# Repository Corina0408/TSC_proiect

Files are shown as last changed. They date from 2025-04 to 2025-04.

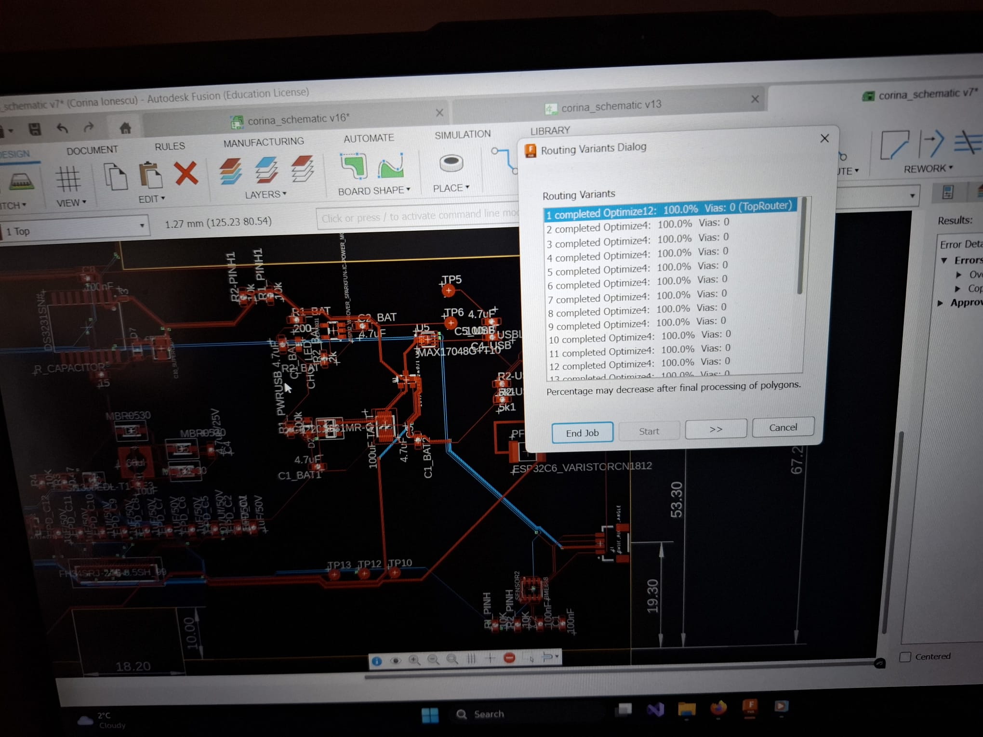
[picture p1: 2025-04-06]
Images/Screenshot 2025-04-06 214750.jpeg

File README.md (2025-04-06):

link diagrama bloc: https://files.fm/u/eejnjsv4u4 

link Bill of Materials: https://docs.google.com/spreadsheets/d/1bhhom45KiLlfx5yxiHwmtoe4DynNoX60qw5_dlvZoLE/edit?usp=sharing 

Descrierea functionalitatii: 

	dispozitiv smart, construit in jurul microcontrollerului ESP32-C6, care integreaza senzori de afisaj OLED, LED RGB pentru vizual, control tactil si un potentiometru.

	Module si componente utilizate

    ESP32-C6: microcontroller principal, care gestioneaza toate componentele, comunicarea si logica dispozitivului

    BME280: senzor de temperatura, umiditate si presiune

    Display OLED (SSD1306): afiseaza informatii de la senzori si statusul sistemului

    LED RGB WS2812B: ofera feedback vizual configurabil

    TTP223: buton tactil folosit pentru interactiuni simple, cum ar fi pornirea luminii sau schimbarea modului de afisare

    Potentiometru: permite reglarea unui parametru analogic

    Reed switch: senzor magnetic digital, detecteaza apropierea unui magnet

	Interfete si comunicatie

    I2C: folosita pentru a conecta atat senzorul BME280, cat si display-ul OLED pe acelasi bus. ESP32-C6 gestioneaza ambele componente fara conflicte.

    PWM/One-wire: pentru LED-ul WS2812B, controlat prin semnal digital specific.

    Digital input: pentru butonul capacitiv si reed switch.

    Analog input (ADC): pentru citirea potentiometrului.

Procesare si comportament

ESP32-C6 colecteaza datele de la senzori si le afiseaza pe ecran. In plus, permite interactiuni tactile si vizuale cu utilizatorul

Descrierea pinilor ESP32-C6:

BME280 (I2C)

    GPIO8 (SDA) – Bus I2C partajat cu display

    GPIO9 (SCL)

OLED SSD1306 (I2C)

    GPIO8 (SDA) – Partajare eficienta de pini

    GPIO9 (SCL)

WS2812B (PWM)

    GPIO7 – Output digital cu timing precis

TTP223 (Digital)

    GPIO6 – Pin liber, ideal pentru input

Potentiometru (Analog)

    GPIO4 (ADC1) – Suporta ADC, masoara tensiune

Reed switch (Digital)

    GPIO5 – Citire stare logica simpla

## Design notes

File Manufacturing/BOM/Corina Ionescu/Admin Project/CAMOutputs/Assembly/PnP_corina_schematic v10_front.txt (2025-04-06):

BOOT_BUTTON	63.88	122.91	180.00		MYBUTTON
C1	158.75	19.05	90.00	100nF	ESP32_WROVER_EAGLE-LTSPICE_C0402
C10	27.43	119.89	270.00	100nF	ESP32_WROVER_EAGLE-LTSPICE_C0402
C10_SUPERCAP	96.52	68.58	270.00	CPH3225A	CAPCP3225X100N
C1_BAT	115.57	68.58	270.00	4.7uF	ESP32_WROVER_EAGLE-LTSPICE_C0402
C1_BAT1	119.38	48.26	180.00	4.7uF	EAGLE-LTSPICE_C0402
C1_BAT2	135.89	52.07	270.00	4.7uF	ESP32_WROVER_EAGLE-LTSPICE_C0402
C2	154.94	19.05	90.00	100nF	ESP32_WROVER_EAGLE-LTSPICE_C0402
C2_BAT	128.27	71.12	0.00	4.7uF	ESP32_WROVER_EAGLE-LTSPICE_C0402
C3	130.81	54.61	270.00	100uF TANT	RCL_CT3528
C4	102.49	51.69	90.00	4.7uF/25V	ESP32_WROVER_EAGLE-LTSPICE_C0402
C4_USB	148.59	68.58	180.00	100nF	EAGLE-LTSPICE_C0402
C5	52.58	119.13	270.00	1uF	ESP32_WROVER_EAGLE-LTSPICE_C0402
C5_USB	148.59	71.12	180.00	4.7uF	EAGLE-LTSPICE_C0402
C6	67.31	119.13	270.00	100nF	ESP32_WROVER_EAGLE-LTSPICE_C0402
C7	89.79	46.36	0.00	10uF	ESP32_WROVER_EAGLE-LTSPICE_C0402
C8	86.36	80.01	0.00	100nF	ESP32_WROVER_EAGLE-LTSPICE_C0402
C9	20.83	100.84	0.00	100nF	EAGLE-LTSPICE_C0402
CHANGE_BUTTON	24.13	122.91	180.00		MYBUTTON
CHG_LED	118.11	68.58	180.00		ADAFRUIT_CHIP-LED0603
C_DELAY	45.72	111.76	270.00	100nF	ESP32_WROVER_EAGLE-LTSPICE_C0402
D1	155.70	66.42	0.00	USBLC6-2SC6Y	SOT95P280X145-6N
D10	33.91	41.53	90.00	PGB1010603MR	DIOC1608X36N
D11	29.46	41.91	90.00	PGB1010603MR	DIOC1608X36N
D12	24.89	42.04	90.00	PGB1010603MR	DIOC1608X36N
D2	118.36	54.99	270.00	ESP32_WROVER_AVX---SD0805S020S1R0_AVX_SD0805S020S1R0_0_0AVX_SD0805S020S1R0_0_0	ESP32_WROVER_AVX---SD0805S020S1R0_AVX_SD0805S020S1R0_0
D3	89.92	55.37	0.00	MBR0530	SOD3716X135N
D4	97.79	48.26	0.00	MBR0530	SOD3716X135N
D5	97.79	52.07	0.00	MBR0530	SOD3716X135N
D6	42.93	41.27	90.00	PGB1010603MR	DIOC1608X36N
D7	92.71	68.58	90.00	ESP32_WROVER_AVX---SD0805S020S1R0_AVX_SD0805S020S1R0_0_0AVX_SD0805S020S1R0_0_0	ESP32_WROVER_AVX---SD0805S020S1R0_AVX_SD0805S020S1R0_0
D8	20.70	42.16	90.00	PGB1010603MR	DIOC1608X36N
D9	38.35	41.40	90.00	PGB1010603MR	DIOC1608X36N
EPD_C1	107.95	38.10	90.00	1uF/50V	ESP32_WROVER_EAGLE-LTSPICE_C0402
EPD_C10	82.55	38.10	90.00	1Uf/50V	ESP32_WROVER_EAGLE-LTSPICE_C0402
EPD_C11	78.74	38.10	90.00	1uF/50V	ESP32_WROVER_EAGLE-LTSPICE_C0402
EPD_C12	74.93	38.10	90.00	1uF/50V	ESP32_WROVER_EAGLE-LTSPICE_C0402
EPD_C2	105.41	38.10	90.00	1uF/50V	ESP32_WROVER_EAGLE-LTSPICE_C0402
EPD_C5	101.60	38.10	90.00	01/Uf/50V	ESP32_WROVER_EAGLE-LTSPICE_C0402
EPD_C6	97.79	38.10	90.00	1uF/50V	ESP32_WROVER_EAGLE-LTSPICE_C0402
EPD_C7	93.98	38.10	90.00	1UF/50V	ESP32_WROVER_EAGLE-LTSPICE_C0402
EPD_C8	90.17	38.10	90.00	1uF/50V	ESP32_WROVER_EAGLE-LTSPICE_C0402
EPD_C9	86.36	38.10	90.00	1uF/50V	ESP32_WROVER_EAGLE-LTSPICE_C0402
IC1	41.91	111.76	0.00	BD5229G-TR	SOT95P280X120-5N
IC4	121.92	54.61	0.00	XC6220A331MR-G	SOT95P280X120-5N
J1	167.09	33.27	90.00	QWIIC_RIGHT_ANGLE	JST04_1MM_RA
J2	165.83	67.06	90.00	SAMACSYS_PARTS_USB4110-GF-A	SAMACSYS_PARTS_USB4110GFA
J3	83.82	30.68	0.00	FH34SRJ-24S-0.5SH_99_	FH34SRJ24S05SH99
J4	8.35	102.96	270.00	112A-TAAR-R03_ATTEND	112ATAARR03ATTEND
L1	90.04	50.04	0.00	68uH	IND_4828-WE-TPC_WRE
MCP73831	123.70	70.48	90.00	ESP32_WROVER_SPARKFUN-IC-POWER_MCP73831	ESP32_WROVER_SPARKFUN-IC-POWER_SOT23-5
PFMF.050.1	153.67	49.53	0.00	ESP32C6_VARISTORCN1812	ESP32C6_VARISTOR_CT/CN1812
Q1	134.62	62.28	0.00	20V/4.2A/52mΩ/1.4W	ESP32_WROVER_SPARKFUN-DISCRETESEMI_SOT23-3
Q2	71.17	39.37	270.00	20V/4.2A/52mΩ/1.4W	ESP32_WROVER_SPARKFUN-DISCRETESEMI_SOT23-3
Q3	82.55	47.24	0.00	SI1308EDL-T1-GE3	SOT65P210X110-3N
R1	20.32	55.88	90.00	10k	ESP32_WROVER_EAGLE-LTSPICE_R0402
R10	43.82	47.75	90.00	10k	ESP32_WROVER_EAGLE-LTSPICE_R0402
R1_BAT	118.11	72.39	0.00	200	ESP32_WROVER_EAGLE-LTSPICE_R0402
R1_PINH1	114.43	76.33	90.00	10k	ESP32_WROVER_EAGLE-LTSPICE_R0402
R1_PWRUSB	115.57	54.61	90.00	100k	ESP32_WROVER_EAGLE-LTSPICE_R0402
R2	63.50	30.48	0.00	2.2	ESP32_WROVER_EAGLE-LTSPICE_R0402
R2-PINH1	110.24	76.20	90.00	10k	ESP32_WROVER_EAGLE-LTSPICE_R0402
R2-USB	149.86	58.42	0.00	5k1	ESP32_WROVER_EAGLE-LTSPICE_R0402
R2-USB1	149.86	60.96	0.00	5k1	ESP32_WROVER_EAGLE-LTSPICE_R0402
R2_BAT	121.92	66.04	90.00	2k	ESP32_WROVER_EAGLE-LTSPICE_R0402
R2_PINH	151.13	19.05	90.00	10K	ESP32_WROVER_EAGLE-LTSPICE_R0402
R3	77.47	46.99	90.00	0.47	ESP32_WROVER_EAGLE-LTSPICE_R0402
R4	73.66	46.99	90.00	10K	ESP32_WROVER_EAGLE-LTSPICE_R0402
R5	34.04	47.88	90.00	10k	ESP32_WROVER_EAGLE-LTSPICE_R0402
R6	29.34	48.13	90.00	10k	ESP32_WROVER_EAGLE-LTSPICE_R0402
R7	24.77	48.26	270.00	10k	ESP32_WROVER_EAGLE-LTSPICE_R0402
R8	20.70	48.39	90.00	10k	ESP32_WROVER_EAGLE-LTSPICE_R0402
R9	38.73	47.88	90.00	10k	ESP32_WROVER_EAGLE-LTSPICE_R0402
RESET_BUTTON1	49.28	122.91	180.00		MYBUTTON
RI_PINH	147.32	19.05	90.00	10K	ESP32_WROVER_EAGLE-LTSPICE_R0402
R_BOOT	60.97	119.38	270.00	10K	ESP32_WROVER_EAGLE-LTSPICE_R0402
R_CAPACITOR	86.36	64.77	0.00	15	ESP32_WROVER_EAGLE-LTSPICE_R0402
R_CHANGE	20.83	120.02	270.00	10K	ESP32_WROVER_EAGLE-LTSPICE_R0402
R_CL1	67.31	39.37	90.00	10K	ESP32_WROVER_EAGLE-LTSPICE_R0402
R_RESET	45.72	119.38	270.00	10K	ESP32_WROVER_EAGLE-LTSPICE_R0402
SENSOR2	153.68	25.40	90.00	BME688	ESP32_WROVER_BME680_PSON80P300X300X100-8N
SJ1	63.50	33.02	0.00		SJ
TP1	55.88	97.79	0.00	TPTP20R	TP20R
TP10	130.81	29.21	0.00	TPTP20R	TP20R
TP11	60.96	97.79	0.00	TPTP20R	TP20R
TP12	125.73	29.21	0.00	TPTP20R	TP20R
TP13	120.65	29.21	0.00	TPTP20R	TP20R
TP14	29.21	31.75	0.00	TPTP20R	TP20R
TP15	22.86	31.75	0.00	TPTP20R	TP20R
TP16	16.51	31.75	0.00	TPTP20R	TP20R
TP17	10.16	31.75	0.00	TPTP20R	TP20R
TP2	20.83	25.27	0.00	TPTP20R	TP20R
TP3	16.51	25.40	0.00	TPTP20R	TP20R
TP4	12.70	25.40	0.00	TPTP20R	TP20R
TP5	142.11	76.20	0.00	TPTP20R	TP20R
TP6	142.24	71.12	0.00	TPTP20R	TP20R
TP7	85.09	121.92	0.00	TPTP20R	TP20R
TP8	80.01	121.92	0.00	TPTP20R	TP20R
TP9	74.93	121.92	0.00	TPTP20R	TP20R
U1	41.91	72.39	0.00	W25Q512JVEIQ	SON127P600X800X80-9N
U2	16.14	71.76	90.00	ESP32-C6-WROOM-1-N8	XCVR_ESP32-C6-WROOM-1-N8
U3	85.09	72.39	270.00	DS3231SN#	SOIC127P1032X265-16N
U5	138.43	68.58	0.00	MAX17048G+T10	SON50P200X200X80-9N

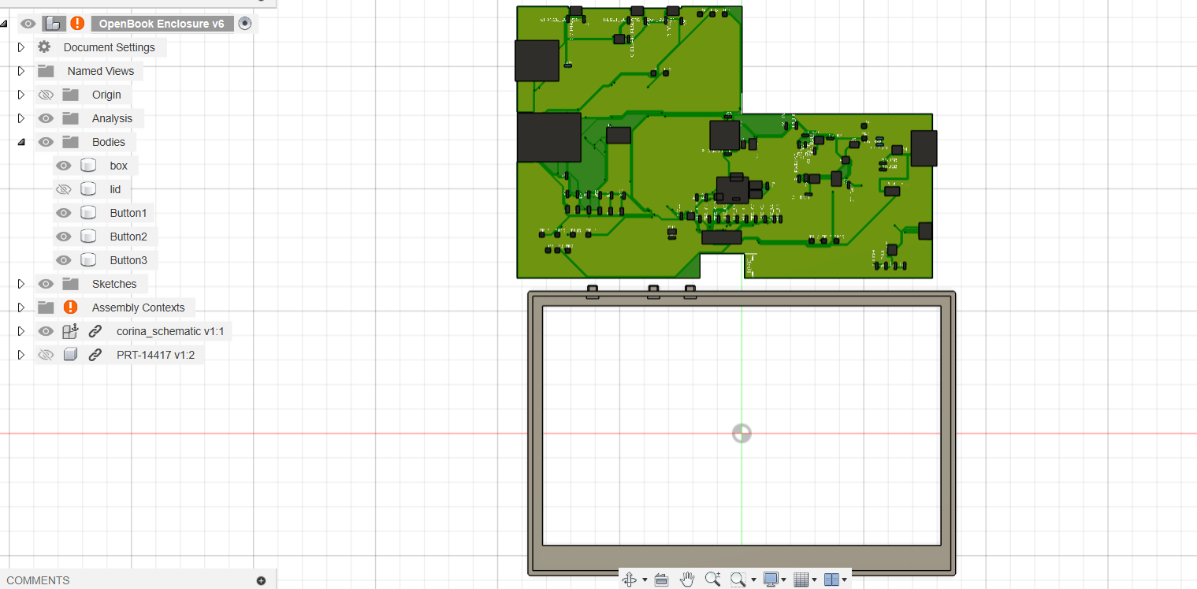
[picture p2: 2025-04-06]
Images/Screenshot 2025-04-06 214743.png

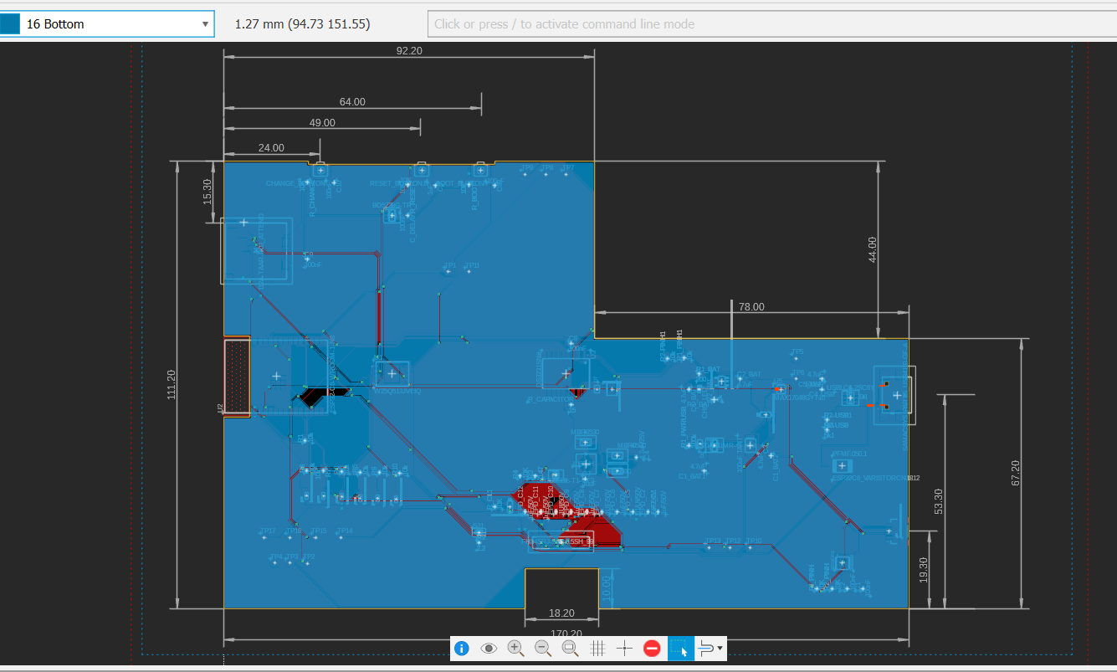
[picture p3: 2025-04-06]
Images/Screenshot 2025-04-06 213727.png

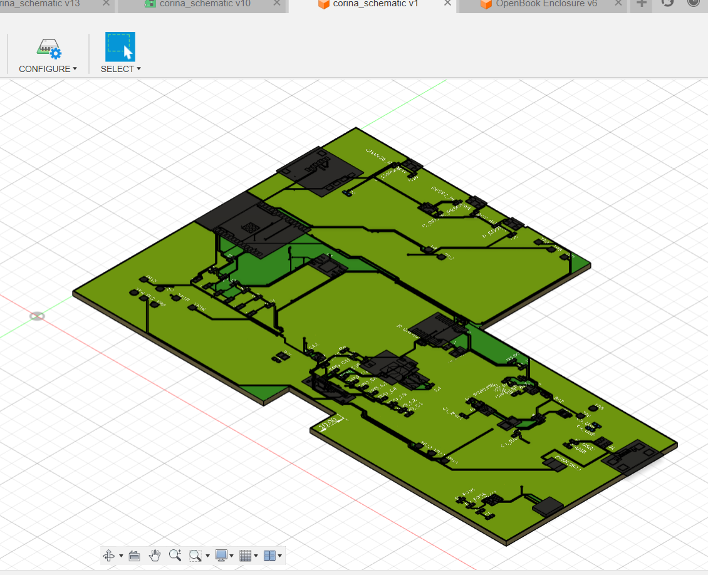
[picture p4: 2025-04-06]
Images/Screenshot 2025-04-06 214116.png

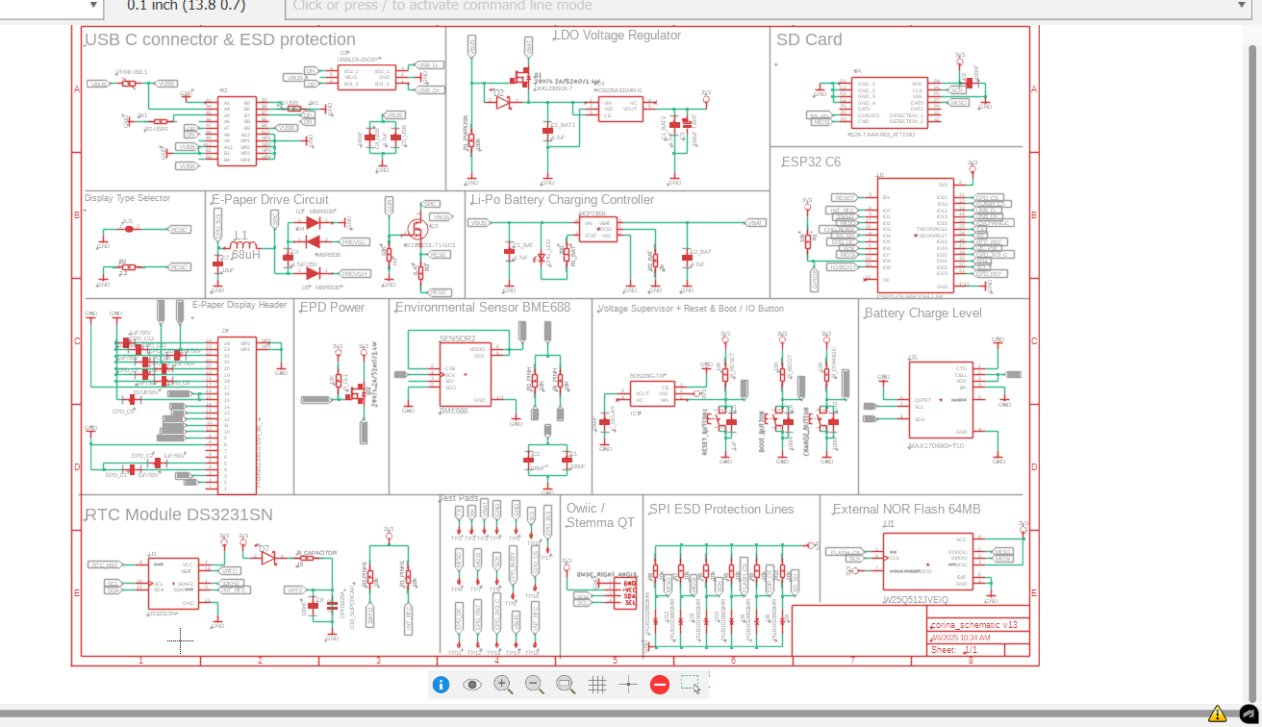
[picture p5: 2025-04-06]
Images/Screenshot 2025-04-06 213624.png

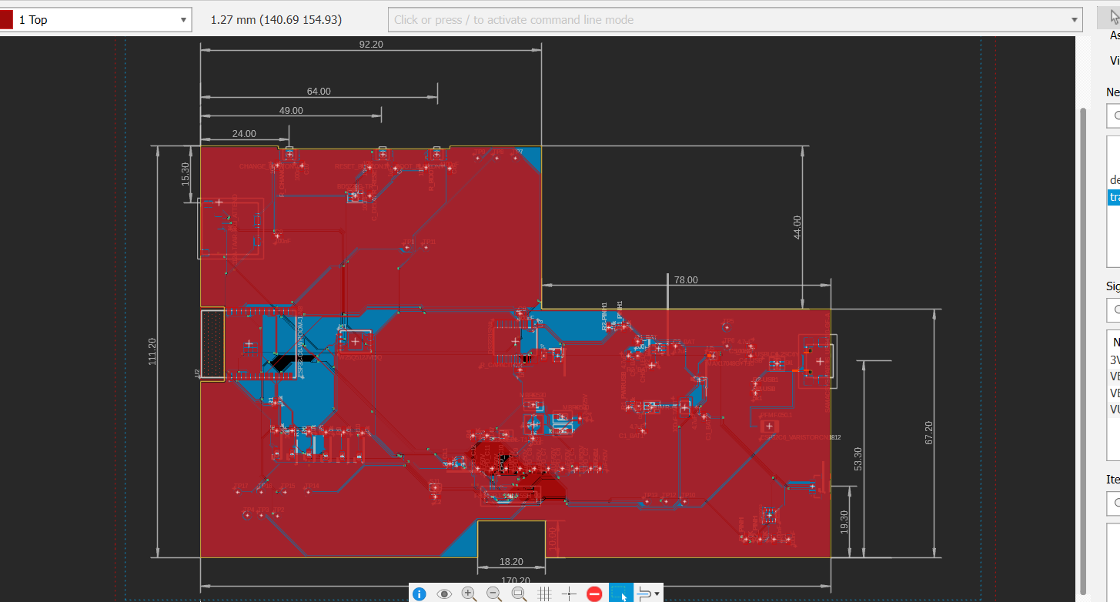
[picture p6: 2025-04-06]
Images/Screenshot 2025-04-06 213659.png

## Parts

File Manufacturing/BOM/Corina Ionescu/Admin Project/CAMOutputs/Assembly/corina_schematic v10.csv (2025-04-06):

Qty | Value | Device | Package | Parts | Description | ARROW_PART_NUMBER | ARROW_PRICE-STOCK | AVAILABILITY | CENTROID_NOT_SPECIFIED | CHECK_PRICES | COPYRIGHT | DATASHEET | DESCRIPTION | DIGIKEY_DESCRIPTION | DIGIKEY_PART_NUMBER | HEIGHT | LEAD_FREE | MANUFACTURER_NAME | MANUFACTURER_PART_NUMBER | MF | MFR_NAME | MOUSER_PART_NUMBER | MOUSER_PRICE-STOCK | MOUSER_TESTING_PART_NUMBER | MOUSER_TESTING_PRICE-STOCK | MP | MPN | PACKAGE | POPULARITY | PREFIX | PRICE | PROD_ID | PURCHASE-URL | ROHS | SNAPEDA_LINK | SPICEMODEL | SPICEPREFIX | TEMPERATURE_RANGE_HIGH | TEMPERATURE_RANGE_LOW | TP_SIGNAL_NAME | VALUE
1 |  | ADAFRUIT_LEDCHIP-LED0603 | ADAFRUIT_CHIP-LED0603 | CHG_LED | LED
3 |  | BUTTON_CUSYOMV1 | MYBUTTON | BOOT_BUTTON, CHANGE_BUTTON, RESET_BUTTON1
1 |  | SJ | SJ | SJ1 | SMD solder JUMPER |  |  |  |  |  |  |  |  |  |  |  |  |  |  |  |  |  |  |  |  |  |  |  | 3
1 | 0.47 | ESP32_WROVER_EAGLE-LTSPICE_RR0402 | ESP32_WROVER_EAGLE-LTSPICE_R0402 | R3 | RESISTOR, European symbol |  |  |  |  |  |  |  |  |  |  |  |  |  |  |  |  |  |  |  |  |  |  |  |  |  |  |  |  |  |  | NONE | R
1 | 01/Uf/50V | ESP32_WROVER_EAGLE-LTSPICE_CC0402 | ESP32_WROVER_EAGLE-LTSPICE_C0402 | EPD_C5 | CAPACITOR, European symbol |  |  |  |  |  |  |  |  |  |  |  |  |  |  |  |  |  |  |  |  |  |  |  |  |  |  |  |  |  |  | NONE | C
1 | 100k | ESP32_WROVER_EAGLE-LTSPICE_RR0402 | ESP32_WROVER_EAGLE-LTSPICE_R0402 | R1_PWRUSB | RESISTOR, European symbol |  |  |  |  |  |  |  |  |  |  |  |  |  |  |  |  |  |  |  |  |  |  |  |  |  |  |  |  |  |  | NONE | R
2 | 100nF | EAGLE-LTSPICE_CC0402 | EAGLE-LTSPICE_C0402 | C4_USB, C9 | CAPACITOR, European symbol |  |  |  |  |  |  |  |  |  |  |  |  |  |  |  |  |  |  |  |  |  |  |  |  |  |  |  |  |  |  | NONE | C
6 | 100nF | ESP32_WROVER_EAGLE-LTSPICE_CC0402 | ESP32_WROVER_EAGLE-LTSPICE_C0402 | C1, C2, C6, C8, C10, C_DELAY | CAPACITOR, European symbol |  |  |  |  |  |  |  |  |  |  |  |  |  |  |  |  |  |  |  |  |  |  |  |  |  |  |  |  |  |  | NONE | C
1 | 100uF TANT | RCL_CPOL-EUCT3528 | RCL_CT3528 | C3 | POLARIZED CAPACITOR, European symbol |  |  |  |  |  |  |  |  |  |  |  |  |  |  |  |  |  |  |  |  |  |  |  | 0 |  |  |  |  |  |  |  | C
7 | 10K | ESP32_WROVER_EAGLE-LTSPICE_RR0402 | ESP32_WROVER_EAGLE-LTSPICE_R0402 | R2_PINH, R4, RI_PINH, R_BOOT, R_CHANGE, R_CL1, R_RESET | RESISTOR, European symbol |  |  |  |  |  |  |  |  |  |  |  |  |  |  |  |  |  |  |  |  |  |  |  |  |  |  |  |  |  |  | NONE | R
9 | 10k | ESP32_WROVER_EAGLE-LTSPICE_RR0402 | ESP32_WROVER_EAGLE-LTSPICE_R0402 | R1, R1_PINH1, R2-PINH1, R5, R6, R7, R8, R9, R10 | RESISTOR, European symbol |  |  |  |  |  |  |  |  |  |  |  |  |  |  |  |  |  |  |  |  |  |  |  |  |  |  |  |  |  |  | NONE | R
1 | 10uF | ESP32_WROVER_EAGLE-LTSPICE_CC0402 | ESP32_WROVER_EAGLE-LTSPICE_C0402 | C7 | CAPACITOR, European symbol |  |  |  |  |  |  |  |  |  |  |  |  |  |  |  |  |  |  |  |  |  |  |  |  |  |  |  |  |  |  | NONE | C
1 | 112A-TAAR-R03_ATTEND | 112A-TAAR-R03_ATTEND | 112ATAARR03ATTEND | J4 | Micro SD Card Socket, Push-Push Type, Top Mount, SMT, H=1.83mm, 10u |  |  |  |  |  |  |  | Micro SD Card Socket | Push-Push Type | Top Mount | SMT | H=1.83mm | 10u |  |  | 1.9mm |  | ATTEND | 112A-TAAR-R03 ATTEND
1 | 15 | ESP32_WROVER_EAGLE-LTSPICE_RR0402 | ESP32_WROVER_EAGLE-LTSPICE_R0402 | R_CAPACITOR | RESISTOR, European symbol |  |  |  |  |  |  |  |  |  |  |  |  |  |  |  |  |  |  |  |  |  |  |  |  |  |  |  |  |  |  | NONE | R
1 | 1UF/50V | ESP32_WROVER_EAGLE-LTSPICE_CC0402 | ESP32_WROVER_EAGLE-LTSPICE_C0402 | EPD_C7 | CAPACITOR, European symbol |  |  |  |  |  |  |  |  |  |  |  |  |  |  |  |  |  |  |  |  |  |  |  |  |  |  |  |  |  |  | NONE | C
1 | 1Uf/50V | ESP32_WROVER_EAGLE-LTSPICE_CC0402 | ESP32_WROVER_EAGLE-LTSPICE_C0402 | EPD_C10 | CAPACITOR, European symbol |  |  |  |  |  |  |  |  |  |  |  |  |  |  |  |  |  |  |  |  |  |  |  |  |  |  |  |  |  |  | NONE | C
1 | 1uF | ESP32_WROVER_EAGLE-LTSPICE_CC0402 | ESP32_WROVER_EAGLE-LTSPICE_C0402 | C5 | CAPACITOR, European symbol |  |  |  |  |  |  |  |  |  |  |  |  |  |  |  |  |  |  |  |  |  |  |  |  |  |  |  |  |  |  | NONE | C
7 | 1uF/50V | ESP32_WROVER_EAGLE-LTSPICE_CC0402 | ESP32_WROVER_EAGLE-LTSPICE_C0402 | EPD_C1, EPD_C2, EPD_C6, EPD_C8, EPD_C9, EPD_C11, EPD_C12 | CAPACITOR, European symbol |  |  |  |  |  |  |  |  |  |  |  |  |  |  |  |  |  |  |  |  |  |  |  |  |  |  |  |  |  |  | NONE | C
1 | 2.2 | ESP32_WROVER_EAGLE-LTSPICE_RR0402 | ESP32_WROVER_EAGLE-LTSPICE_R0402 | R2 | RESISTOR, European symbol |  |  |  |  |  |  |  |  |  |  |  |  |  |  |  |  |  |  |  |  |  |  |  |  |  |  |  |  |  |  | NONE | R
1 | 200 | ESP32_WROVER_EAGLE-LTSPICE_RR0402 | ESP32_WROVER_EAGLE-LTSPICE_R0402 | R1_BAT | RESISTOR, European symbol |  |  |  |  |  |  |  |  |  |  |  |  |  |  |  |  |  |  |  |  |  |  |  |  |  |  |  |  |  |  | NONE | R
2 | 20V/4.2A/52mO/1.4W | ESP32_WROVER_SPARKFUN-DISCRETESEMI_MOSFET_PCH-DMG2305UX-7 | ESP32_WROVER_SPARKFUN-DISCRETESEMI_SOT23-3 | Q1, Q2 | P-channel MOSFETs |  |  |  |  |  |  |  |  |  |  |  |  |  |  |  |  |  |  |  |  |  |  |  |  |  |  | TRAN-14388 |  |  |  |  |  |  |  |  | 20V/4.2A/52mO/1.4W
1 | 2k | ESP32_WROVER_EAGLE-LTSPICE_RR0402 | ESP32_WROVER_EAGLE-LTSPICE_R0402 | R2_BAT | RESISTOR, European symbol |  |  |  |  |  |  |  |  |  |  |  |  |  |  |  |  |  |  |  |  |  |  |  |  |  |  |  |  |  |  | NONE | R
2 | 4.7uF | EAGLE-LTSPICE_CC0402 | EAGLE-LTSPICE_C0402 | C1_BAT1, C5_USB | CAPACITOR, European symbol |  |  |  |  |  |  |  |  |  |  |  |  |  |  |  |  |  |  |  |  |  |  |  |  |  |  |  |  |  |  | NONE | C
3 | 4.7uF | ESP32_WROVER_EAGLE-LTSPICE_CC0402 | ESP32_WROVER_EAGLE-LTSPICE_C0402 | C1_BAT, C1_BAT2, C2_BAT | CAPACITOR, European symbol |  |  |  |  |  |  |  |  |  |  |  |  |  |  |  |  |  |  |  |  |  |  |  |  |  |  |  |  |  |  | NONE | C
1 | 4.7uF/25V | ESP32_WROVER_EAGLE-LTSPICE_CC0402 | ESP32_WROVER_EAGLE-LTSPICE_C0402 | C4 | CAPACITOR, European symbol |  |  |  |  |  |  |  |  |  |  |  |  |  |  |  |  |  |  |  |  |  |  |  |  |  |  |  |  |  |  | NONE | C
2 | 5k1 | ESP32_WROVER_EAGLE-LTSPICE_RR0402 | ESP32_WROVER_EAGLE-LTSPICE_R0402 | R2-USB, R2-USB1 | RESISTOR, European symbol |  |  |  |  |  |  |  |  |  |  |  |  |  |  |  |  |  |  |  |  |  |  |  |  |  |  |  |  |  |  | NONE | R
1 | 68uH | 744043680IND_4828-WE-TPC_WRE | IND_4828-WE-TPC_WRE | L1 |  |  |  |  |  |  | Copyright (C) 2024 Ultra Librarian. All rights reserved. |  |  |  |  |  |  |  | 744043680 |  | Wurth Electronics
1 | BD5229G-TR | XC6220A331MR-G | SOT95P280X120-5N | IC1 | LDO Voltage Regulators |  |  |  |  |  |  |  | LDO Voltage Regulators |  |  | 1.2mm |  | Torex | XC6220A331MR-G |  |  | 865-XC6220A331MR-G | https://www.mouser.co.uk/ProductDetail/Torex-Semiconductor/XC6220A331MR-G?qs=AsjdqWjXhJ8ZSWznL1J0gg%3D%3D
1 | BME688 | ESP32_WROVER_BME680_BME680 | ESP32_WROVER_BME680_PSON80P300X300X100-8N | SENSOR2 | Integrated Environmental Unit |  |  | Unavailable |  |  |  |  | Integrated Environmental Unit |  |  |  |  |  |  | Bosch Sensortec |  |  |  |  |  | BME680 |  | LGA-8 Bosch Tools |  |  | None
1 | CPH3225A | CPH3225A | CAPCP3225X100N | C10_SUPERCAP | Cap 0.011F 3.3V 1210 Flat Check availability |  |  | Not in stock |  | https://www.snapeda.com/parts/CPH3225A/Seiko+Instruments/view-part/?ref=eda |  |  | 11 mF (EDLC) Supercapacitor 3.3 V 1210 (3225 Metric) - - |  |  |  |  |  |  | Seiko Instruments |  |  |  |  |  | CPH3225A |  | 1210 Seiko |  |  | None |  | https://www.snapeda.com/api/url_track_click_mouser/?unipart_id=562593&manufacturer=Seiko Instruments&part_name=CPH3225A&search_term=None |  | https://www.snapeda.com/parts/CPH3225A/Seiko+Instruments/view-part/?ref=snap
1 | DS3231SN# | DS3231SN# | SOIC127P1032X265-16N | U3 | Real Time Clock Serial 16-Pin SOIC W T/R Check availability |  |  | In Stock |  | https://www.snapeda.com/parts/DS3231SN%23/Analog+Devices/view-part/?ref=eda |  |  | Extremely Accurate I²C-Integrated RTC/TCXO/Crystal |  |  |  |  |  |  | Analog Devices |  |  |  |  |  | DS3231SN# |  | SOIC-16 Maxim |  |  | None |  | https://www.snapeda.com/api/url_track_click_mouser/?unipart_id=99048&manufacturer=Analog Devices&part_name=DS3231SN#&search_term=None |  | https://www.snapeda.com/parts/DS3231SN%23/Analog+Devices/view-part/?ref=snap
1 | ESP32-C6-WROOM-1-N8 | ESP32-C6-WROOM-1-N8 | XCVR_ESP32-C6-WROOM-1-N8 | U2 | Check availability |  |  | In Stock |  | https://www.snapeda.com/parts/ESP32-C6-WROOM-1-N8/Espressif+Systems/view-part/?ref=eda |  |  | Multiprotocol Modules ESP32-C6 module | Wi-Fi 6 in 2.4 GHz band | Bluetooth 5 | Zigbee 3.0 and Thread. ESP34-WROOM Compatible - ENGINEERING SAMPLE |  |  |  |  |  |  | Espressif Systems |  |  |  |  |  | ESP32-C6-WROOM-1-N8 |  | None |  |  | None |  |  |  | https://www.snapeda.com/parts/ESP32-C6-WROOM-1-N8/Espressif+Systems/view-part/?ref=snap
1 | ESP32C6_VARISTORCN1812 | ESP32C6_VARISTORCN1812 | ESP32C6_VARISTOR_CT/CN1812 | PFMF.050.1 | VARISTOR |  |  |  |  |  |  |  |  |  |  |  |  |  |  |  |  |  |  |  |  |  |  |  | 0
2 | ESP32_WROVER_AVX---SD0805S020S1R0_AVX_SD0805S020S1R0_0_0AVX_SD0805S020S1R0_0_0 | ESP32_WROVER_AVX---SD0805S020S1R0_AVX_SD0805S020S1R0_0_0AVX_SD0805S020S1R0_0_0 | ESP32_WROVER_AVX---SD0805S020S1R0_AVX_SD0805S020S1R0_0 | D2, D7 | Schottky Barrier Rectifier Diode |  |  |  | No |  |  | http://datasheets.avx.com/schottky.pdf |  | DIODE SCHOTTKY 20V 1A 0805 | 478-7800-1-ND |  | yes |  |  | AVX |  | 581-SD0805S020S1R0 |  |  |  |  |  | 0805 (2012 metric) |  | D |  |  |  | yes |  |  |  | +125°C | -55°C
1 | ESP32_WROVER_SPARKFUN-IC-POWER_MCP73831 | ESP32_WROVER_SPARKFUN-IC-POWER_MCP73831 | ESP32_WROVER_SPARKFUN-IC-POWER_SOT23-5 | MCP73831 | MCP73831T Li-Ion, Li-Pol Controller |  |  |  |  |  |  |  |  |  |  |  |  |  |  |  |  |  |  |  |  |  |  |  |  |  |  | IC-09995
1 | FH34SRJ-24S-0.5SH_99_ | FH34SRJ-24S-0.5SH_99_ | FH34SRJ24S05SH99 | J3 | (0.50mm) Surface Mount, Right Angle |  |  |  |  |  |  |  | 24 Position FFC | FPC Connector Contacts | (0.50mm) Surface Mount | Right Angle |  |  | 1.1mm |  | Hirose | FH34SRJ-24S-0.5SH(99) |  |  | 798-FH34SRJ24S05SH99 | https://www.mouser.co.uk/ProductDetail/Hirose-Connector/FH34SRJ-24S-0.5SH99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
1 | MAX17048G+T10 | MAX17048G+T10 | SON50P200X200X80-9N | U5 | Check availability |  |  | In Stock |  | https://www.snapeda.com/parts/MAX17048G+T10/Analog+Devices/view-part/?ref=eda |  |  | 3µA 1-Cell/2-Cell Fuel Gauge with ModelGauge |  |  |  |  |  |  | Analog Devices |  |  |  |  |  | MAX17048G+T10 |  | TDFN-8 Maxim |  |  | None |  | https://www.snapeda.com/api/url_track_click_mouser/?unipart_id=329239&manufacturer=Analog Devices&part_name=MAX17048G+T10&search_term=None |  | https://www.snapeda.com/parts/MAX17048G+T10/Analog+Devices/view-part/?ref=snap
3 | MBR0530 | MBR0530 | SOD3716X135N | D3, D4, D5 | ON SEMICONDUCTOR - MBR0530 - DIODE, SCHOTTKY, 0.5A, 30V, SOD-123 |  |  | In Stock |  | https://www.snapeda.com/parts/MBR0530/Onsemi/view-part/?ref=eda |  |  | Diode Schottky 30 V 500mA Surface Mount SOD-123 |  |  |  |  |  |  | ON Semiconductor |  |  |  |  |  | MBR0530 |  | SOD-123-2 ON Semiconductor |  |  | None |  | https://www.snapeda.com/api/url_track_click_mouser/?unipart_id=179458&manufacturer=ON Semiconductor&part_name=MBR0530&search_term=None |  | https://www.snapeda.com/parts/MBR0530/Onsemi/view-part/?ref=snap
6 | PGB1010603MR | PGB1010603MR | DIOC1608X36N | D6, D8, D9, D10, D11, D12 | Check availability |  |  | In Stock |  | https://www.snapeda.com/parts/PGB1010603MR/Littelfuse/view-part/?ref=eda |  |  | 150V (Typ) Clamp - Ipp Tvs Diode Surface Mount 0603 (1608 Metric) |  |  |  |  |  |  | Littelfuse Inc. |  |  |  |  |  | PGB1010603MR |  | 0603 Littelfuse Inc. |  |  | None |  | https://www.snapeda.com/api/url_track_click_mouser/?unipart_id=5659453&manufacturer=Littelfuse Inc.&part_name=PGB1010603MR&search_term=None |  | https://www.snapeda.com/parts/PGB1010603MR/Littelfuse/view-part/?ref=snap
1 | QWIIC_RIGHT_ANGLE | QWIIC_CONNECTORJS-1MM | JST04_1MM_RA | J1 | SparkFun I2C Standard Qwiic Connector |  |  |  |  |  |  |  |  |  |  |  |  |  |  |  |  |  |  |  |  |  |  |  |  |  |  | CONN-13694 |  |  |  |  |  |  |  |  | QWIIC_RIGHT_ANGLE
1 | SAMACSYS_PARTS_USB4110-GF-A | SAMACSYS_PARTS_USB4110-GF-A | SAMACSYS_PARTS_USB4110GFA | J2 | CONN USB 2.0 TYPE-C R/A SMT |  |  |  |  |  |  |  | CONN USB 2.0 TYPE-C R/A SMT |  |  | 3.26mm |  | GCT (GLOBAL CONNECTOR TECHNOLOGY) | USB4110-GF-A |  |  | 640-USB4110-GF-A | https://www.mouser.co.uk/ProductDetail/GCT/USB4110-GF-A?qs=KUoIvG%2F9IlYiZvIXQjyJeA%3D%3D
1 | SI1308EDL-T1-GE3 | SI1308EDL-T1-GE3 | SOT65P210X110-3N | Q3 | MOSFET N-Ch 30V 1.5A TrenchFET SC70 Vishay Si1308EDL-T1-GE3 N-channel MOSFET Transistor, 1.5 A, 30 V, 3-Pin SC-70 |  |  | In Stock |  | https://www.snapeda.com/parts/SI1308EDL-T1-GE3/Vishay+Siliconix/view-part/?ref=eda |  |  | Si1308EDL-T1-GE3 N-channel MOSFET Transistor | 1.5 A | 30 V | 3-Pin SC-70 | Siliconix / Vishay SI1308EDL-T1-GE3 |  |  |  |  |  |  | Vishay Siliconix |  |  |  |  |  | SI1308EDL-T1-GE3 |  | SOT-323 Vishay Semiconductor |  |  | None |  | https://www.snapeda.com/api/url_track_click_mouser/?unipart_id=274603&manufacturer=Vishay Siliconix&part_name=SI1308EDL-T1-GE3&search_term=None |  | https://www.snapeda.com/parts/SI1308EDL-T1-GE3/Vishay+Siliconix/view-part/?ref=snap
17 | TPTP20R | TPTP20R | TP20R | TP1, TP2, TP3, TP4, TP5, TP6, TP7, TP8, TP9, TP10, TP11, TP12, TP13, TP14, TP15, TP16, TP17 | Test pad |  |  |  |  |  |  |  |  |  |  |  |  |  |  |  |  |  |  |  |  |  |  |  | 2
1 | USBLC6-2SC6Y | USBLC6-2SC6Y | SOT95P280X145-6N | D1 | Low Cap. ESD Protection Auto SOT-23-6 STMicroelectronics USBLC6-2SC6Y, Dual Uni-Directional TVS Diode Array, 6-Pin SOT-23 |  |  | In Stock |  | https://www.snapeda.com/parts/USBLC6-2SC6Y/STMicroelectronics/view-part/?ref=eda |  |  | 17V Clamp 5A (8/20µs) Ipp Tvs Diode Surface Mount SOT-23-6 |  |  |  |  |  |  | STMicroelectronics |  |  |  |  |  | USBLC6-2SC6Y |  | SOT-23-6 STMicroelectronics |  |  | None |  |  |  | https://www.snapeda.com/parts/USBLC6-2SC6Y/STMicroelectronics/view-part/?ref=snap
1 | W25Q512JVEIQ | W25Q512JVEIQ | SON127P600X800X80-9N | U1 | Check availability |  |  | In Stock |  | https://www.snapeda.com/parts/W25Q512JVEIQ/Winbond+Electronics/view-part/?ref=eda |  |  | FLASH - NOR Memory IC 512Mb (64M x 8) SPI - Quad I/O 133 MHz 8-WSON (8x6) |  |  |  |  |  |  | Winbond Electronics |  |  |  |  |  | W25Q512JVEIQ |  | Package |  |  | None |  |  |  | https://www.snapeda.com/parts/W25Q512JVEIQ/Winbond+Electronics/view-part/?ref=snap
1 | XC6220A331MR-G | XC6220A331MR-G | SOT95P280X120-5N | IC4 | LDO Voltage Regulators |  |  |  |  |  |  |  | LDO Voltage Regulators |  |  | 1.2mm |  | Torex | XC6220A331MR-G |  |  | 865-XC6220A331MR-G | https://www.mouser.co.uk/ProductDetail/Torex-Semiconductor/XC6220A331MR-G?qs=AsjdqWjXhJ8ZSWznL1J0gg%3D%3D

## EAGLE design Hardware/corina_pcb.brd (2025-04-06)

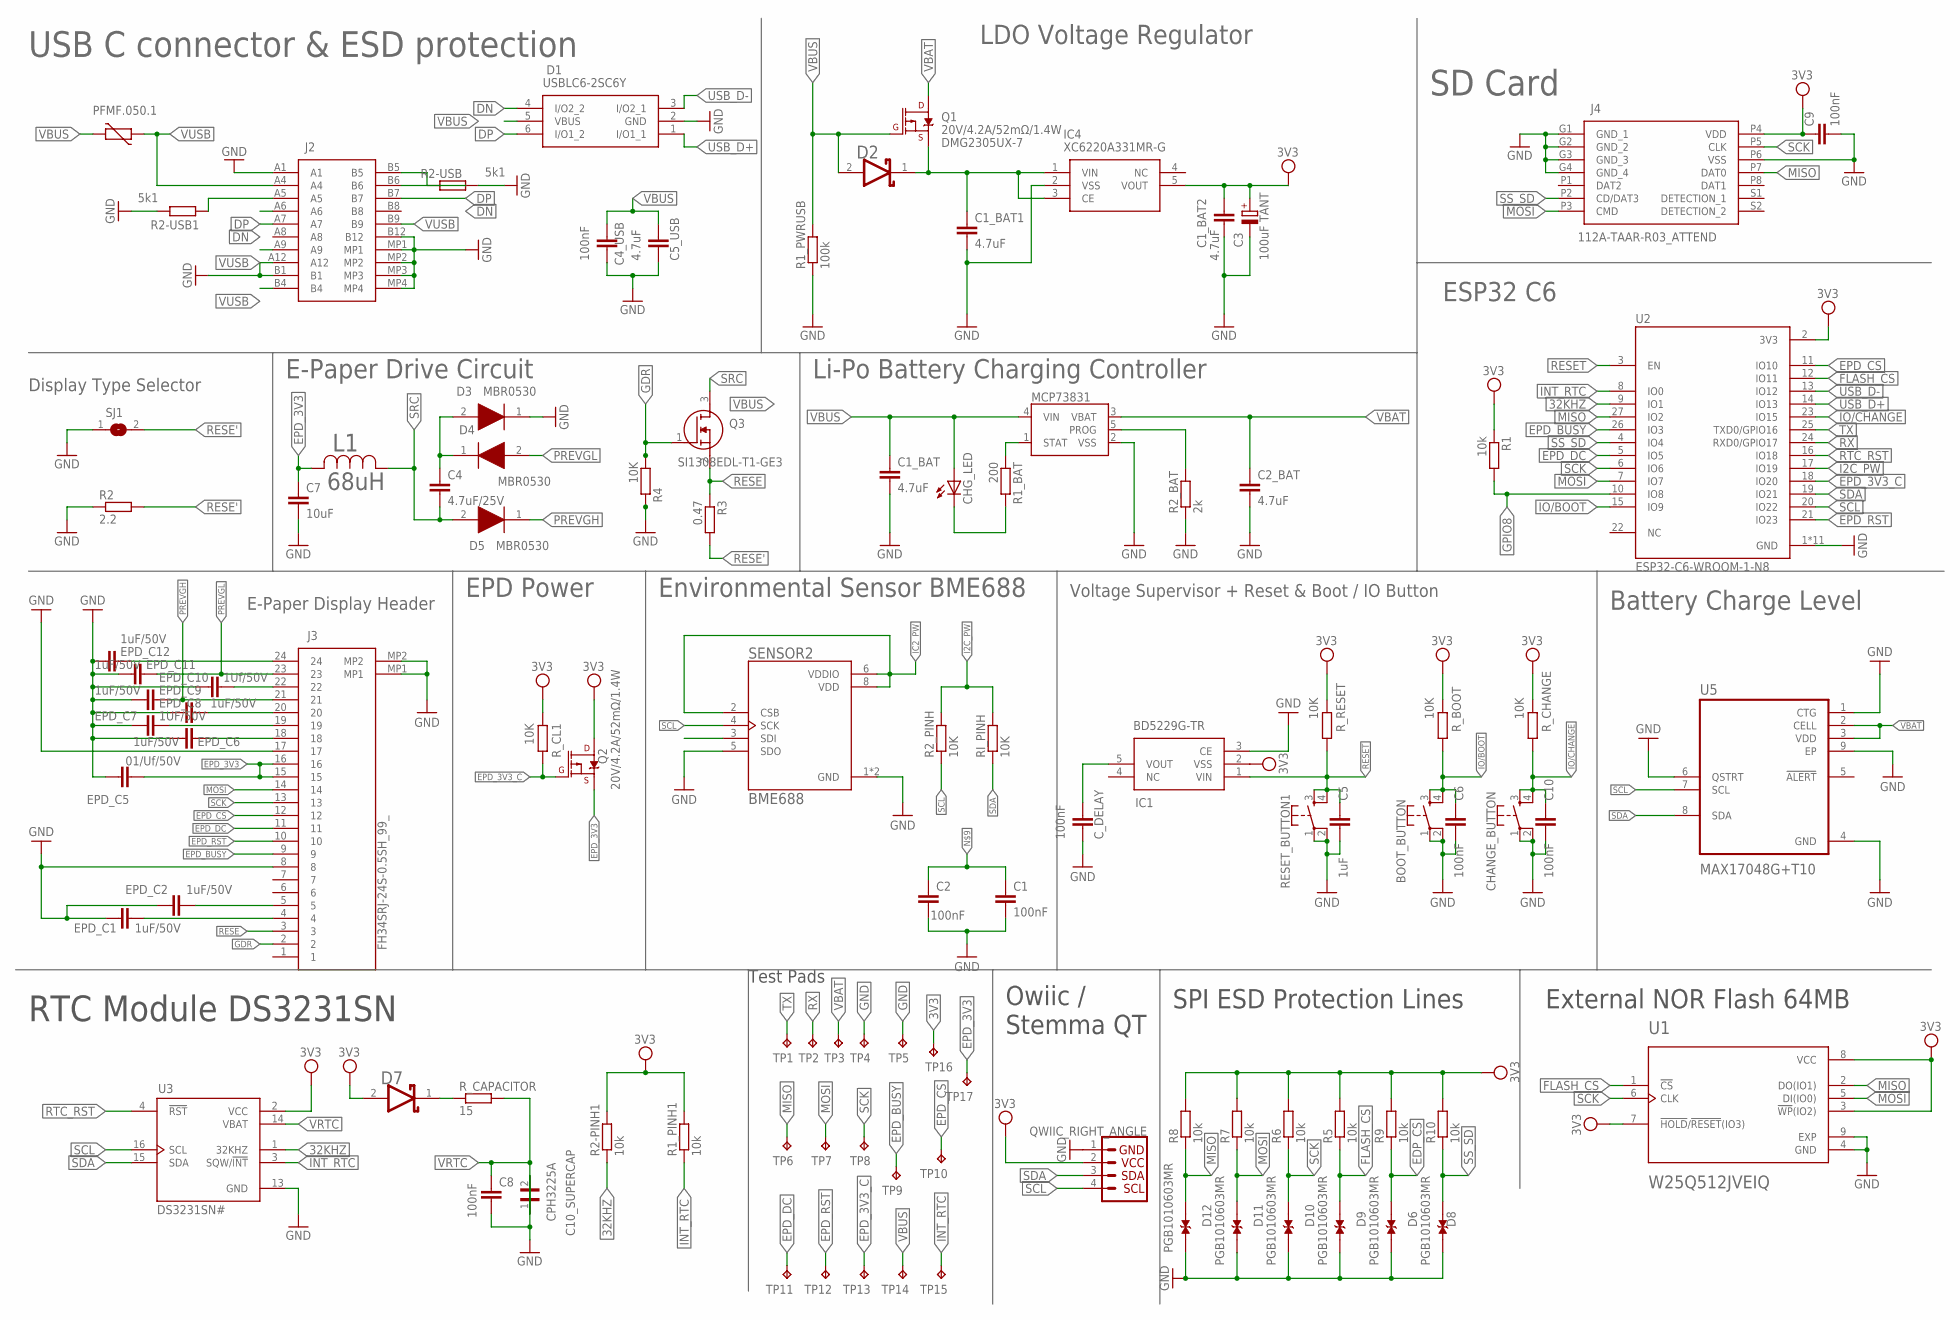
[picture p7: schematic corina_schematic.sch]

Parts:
BOOT_BUTTON: BUTTON_CUSYOMV1; MYBUTTON
C1, C2, C6, C8, C10: 100nF; ESP32_WROVER_EAGLE-LTSPICE_C0402
C1_BAT, C1_BAT2, C2_BAT: 4.7uF; ESP32_WROVER_EAGLE-LTSPICE_C0402
C1_BAT1, C5_USB: 4.7uF; EAGLE-LTSPICE_C0402
C3: 100uF TANT; RCL_CT3528
C4: 4.7uF/25V; ESP32_WROVER_EAGLE-LTSPICE_C0402
C4_USB, C9: 100nF; EAGLE-LTSPICE_C0402
C5: 1uF; ESP32_WROVER_EAGLE-LTSPICE_C0402
C7: 10uF; ESP32_WROVER_EAGLE-LTSPICE_C0402
C10_SUPERCAP: CPH3225A; CAPCP3225X100N
CHANGE_BUTTON: BUTTON_CUSYOMV1; MYBUTTON
CHG_LED: ADAFRUIT_LEDCHIP-LED0603; ADAFRUIT_CHIP-LED0603
C_DELAY: 100nF; ESP32_WROVER_EAGLE-LTSPICE_C0402
D1: USBLC6-2SC6Y; SOT95P280X145-6N
D2, D7: ESP32_WROVER_AVX---SD0805S020S1R0_AVX_SD0805S020S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; ESP32_WROVER_AVX---SD0805S020S1R0_AVX_SD0805S020S1R0_0
D3, D4, D5: MBR0530; SOD3716X135N
D6, D8, D9, D10, D11, D12: PGB1010603MR; DIOC1608X36N
EPD_C1, EPD_C2, EPD_C6, EPD_C8, EPD_C9, EPD_C11, EPD_C12: 1uF/50V; ESP32_WROVER_EAGLE-LTSPICE_C0402
EPD_C5: 01/Uf/50V; ESP32_WROVER_EAGLE-LTSPICE_C0402
EPD_C7: 1UF/50V; ESP32_WROVER_EAGLE-LTSPICE_C0402
EPD_C10: 1Uf/50V; ESP32_WROVER_EAGLE-LTSPICE_C0402
IC1: BD5229G-TR; SOT95P280X120-5N
IC4: XC6220A331MR-G; SOT95P280X120-5N
J1: QWIIC_RIGHT_ANGLE; JST04_1MM_RA
J2: SAMACSYS_PARTS_USB4110-GF-A; SAMACSYS_PARTS_USB4110GFA
J3: FH34SRJ-24S-0.5SH_99_; FH34SRJ24S05SH99
J4: 112A-TAAR-R03_ATTEND; 112ATAARR03ATTEND
L1: 68uH; IND_4828-WE-TPC_WRE
MCP73831: ESP32_WROVER_SPARKFUN-IC-POWER_MCP73831; ESP32_WROVER_SPARKFUN-IC-POWER_SOT23-5
PFMF.050.1: ESP32C6_VARISTORCN1812; ESP32C6_VARISTOR_CT/CN1812
Q1, Q2: 20V/4.2A/52mΩ/1.4W; ESP32_WROVER_SPARKFUN-DISCRETESEMI_SOT23-3
Q3: SI1308EDL-T1-GE3; SOT65P210X110-3N
R1, R1_PINH1, R2-PINH1, R5, R6, R7, R8, R9, R10: 10k; ESP32_WROVER_EAGLE-LTSPICE_R0402
R1_BAT: 200; ESP32_WROVER_EAGLE-LTSPICE_R0402
R1_PWRUSB: 100k; ESP32_WROVER_EAGLE-LTSPICE_R0402
R2: 2.2; ESP32_WROVER_EAGLE-LTSPICE_R0402
R2-USB, R2-USB1: 5k1; ESP32_WROVER_EAGLE-LTSPICE_R0402
R2_BAT: 2k; ESP32_WROVER_EAGLE-LTSPICE_R0402
R2_PINH, R4: 10K; ESP32_WROVER_EAGLE-LTSPICE_R0402
R3: 0.47; ESP32_WROVER_EAGLE-LTSPICE_R0402
RESET_BUTTON1: BUTTON_CUSYOMV1; MYBUTTON
RI_PINH: 10K; ESP32_WROVER_EAGLE-LTSPICE_R0402
R_BOOT: 10K; ESP32_WROVER_EAGLE-LTSPICE_R0402
R_CAPACITOR: 15; ESP32_WROVER_EAGLE-LTSPICE_R0402
R_CHANGE: 10K; ESP32_WROVER_EAGLE-LTSPICE_R0402
R_CL1: 10K; ESP32_WROVER_EAGLE-LTSPICE_R0402
R_RESET: 10K; ESP32_WROVER_EAGLE-LTSPICE_R0402
SENSOR2: BME688; ESP32_WROVER_BME680_PSON80P300X300X100-8N
SJ1: SJ
TP1, TP2, TP3, TP4, TP5, TP6, TP7, TP8, TP9, TP10, TP11, TP12, TP13, TP14, TP15, TP16, TP17: TPTP20R; TP20R
U1: W25Q512JVEIQ; SON127P600X800X80-9N
U2: ESP32-C6-WROOM-1-N8; XCVR_ESP32-C6-WROOM-1-N8
U3: DS3231SN#; SOIC127P1032X265-16N
U5: MAX17048G+T10; SON50P200X200X80-9N

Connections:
3V3: C1_BAT2.1, C3.+, C9.1, D7.2 (ANODE), IC1.2 (VSS), IC4.5 (VOUT), J1.2, J4.P4 (VDD), Q2.3 (D), R1.1, R1_PINH1.2, R2-PINH1.2, R5.2, R6.2, R7.2, R8.2, R9.2, R10.2, R_BOOT.2, R_CHANGE.2, R_CL1.2, R_RESET.2, TP16.TP, U1.3 (!WP!(IO2)), U1.7 (!HOLD!/!RESET!(IO3)), U1.8 (VCC), U2.2 (3V3), U3.2 (VCC)
32KHZ: R2-PINH1.1, U2.9 (IO1), U3.1 (32KHZ)
DN: J2.A7
DP: J2.A6
EDP_CS: D9.2, R9.1
EPD_3V3: C7.1, EPD_C5.2, J3.15, J3.16, L1.2, Q2.2 (S), TP17.TP
EPD_3V3_C: Q2.1 (G), R_CL1.1, TP13.TP, U2.18 (IO20)
EPD_BUSY: J3.9, TP9.TP, U2.26 (IO3)
EPD_CS: J3.12, TP10.TP, U2.11 (IO10)
EPD_DC: J3.11, TP11.TP, U2.5 (IO5)
EPD_RST: J3.10, TP12.TP, U2.21 (IO23)
FLASH_CS: D10.2, R5.1, U1.1 (!CS), U2.12 (IO11)
GDR: J3.2, Q3.1 (G), R4.2
GND: BOOT_BUTTON.1, BOOT_BUTTON.2, C1.2, C1_BAT.2, C1_BAT1.2, C1_BAT2.2, C2.2, C2_BAT.2, C3.-, C4_USB.2, C5.2, C5_USB.2, C6.2, C7.2, C8.2, C9.2, C10.2, C10_SUPERCAP.2, CHANGE_BUTTON.1, CHANGE_BUTTON.2, C_DELAY.2, D1.2 (GND), D3.1 (K), D6.1, D8.1, D9.1, D10.1, D11.1, D12.1, EPD_C1.1, EPD_C2.1, EPD_C5.1, EPD_C6.2, EPD_C7.2, EPD_C8.2, EPD_C9.2, EPD_C10.2, EPD_C11.2, EPD_C12.2, IC1.3 (CE), IC4.2 (VSS), J1.1, J2.A1, J2.A12, J2.B1, J2.B12, J2.MP1, J2.MP2, J2.MP3, J2.MP4, J3.8, J3.17, J3.MP1, J3.MP2, J4.G1 (GND_1), J4.G2 (GND_2), J4.G3 (GND_3), J4.G4 (GND_4), J4.P6 (VSS), MCP73831.2 (VSS), R1_PWRUSB.1, R2.1, R2-USB.2, R2-USB1.1, R2_BAT.1, R4.1, RESET_BUTTON1.1, RESET_BUTTON1.2, SENSOR2.1 (GND), SENSOR2.5 (SDO), SENSOR2.7 (GND), SJ1.1, TP4.TP, TP5.TP, U1.4 (GND), U1.9 (EXP), U2.1 (GND), U2.28 (GND), U2.29_1 (GND), U2.29_2 (GND), U2.29_3 (GND), U2.29_4 (GND), U2.29_5 (GND), U2.29_6 (GND), U2.29_7 (GND), U2.29_8 (GND), U2.29_9 (GND), U3.13 (GND), U5.1 (CTG), U5.4 (GND), U5.6 (QSTRT), U5.9 (EP)
GPIO8: R1.2, U2.10 (IO8)
I2C_PW: R2_PINH.2, RI_PINH.2, U2.17 (IO19)
IC2_PW: SENSOR2.2 (CSB), SENSOR2.6 (VDDIO), SENSOR2.8 (VDD)
INT_RTC: R1_PINH1.1, TP15.TP, U2.8 (IO0), U3.3 (SQW/!INT)
IO/BOOT: BOOT_BUTTON.3, BOOT_BUTTON.4, C6.1, R_BOOT.1, U2.15 (IO9)
IO/CHANGE: C10.1, CHANGE_BUTTON.3, CHANGE_BUTTON.4, R_CHANGE.1, U2.23 (IO15)
MISO: D8.2, J4.P7 (DAT0), R8.1, TP6.TP, U1.2 (DO(IO1))
MOSI: D12.2, J3.14, J4.P3 (CMD), R7.1, TP7.TP, U1.5 (DI(IO0))
unnamed: D7.1 (CATHODE), R_CAPACITOR.1
unnamed: J2.B5, R2-USB.1
unnamed: J2.A5, R2-USB1.2
unnamed: C1.1, C2.1
unnamed: C4_USB.1, C5_USB.1
unnamed: C1_BAT1.1, D2.1 (CATHODE), IC4.1 (VIN), IC4.3 (CE), Q1.2 (S)
unnamed: D2.2 (ANODE), Q1.1 (G), R1_PWRUSB.2
unnamed: C4.2, D5.2 (A), L1.1
unnamed: C4.1, D3.2 (A), D4.1 (K)
unnamed: MCP73831.1 (STAT), R1_BAT.1
unnamed: CHG_LED.C, R1_BAT.2
unnamed: C1_BAT.1, CHG_LED.A, MCP73831.4 (VIN)
unnamed: MCP73831.5 (PROG), R2_BAT.2
unnamed: EPD_C1.2, J3.4
unnamed: EPD_C2.2, J3.5
unnamed: EPD_C6.1, J3.18
unnamed: EPD_C7.1, J3.19
unnamed: EPD_C8.1, J3.20
unnamed: EPD_C10.1, J3.22
unnamed: EPD_C12.1, J3.24
unnamed: C_DELAY.1, IC1.5 (VOUT)
PREVGH: D5.1 (K), EPD_C9.1, J3.21
PREVGL: D4.2 (A), EPD_C11.1, J3.23
RESE: J3.3, Q3.2 (S), R3.1
RESE': SJ1.2
RESET: C5.1, IC1.1 (VIN), RESET_BUTTON1.3, RESET_BUTTON1.4, R_RESET.1, U2.3 (EN)
RTC_RST: U2.16 (IO18), U3.4 (!RST)
RX: TP2.TP, U2.24 (RXD0/GPIO17)
SCK: D11.2, J3.13, J4.P5 (CLK), R6.1, TP8.TP, U1.6 (CLK)
SCL: J1.4, R2_PINH.1, SENSOR2.4 (SCK), U2.20 (IO22), U3.16 (SCL), U5.7 (SCL)
SDA: J1.3, RI_PINH.1, SENSOR2.3 (SDI), U2.19 (IO21), U3.15 (SDA), U5.8 (SDA)
SRC: Q3.3 (D)
SS_SD: D6.2, J4.P2 (CD/DAT3), R10.1
TX: TP1.TP, U2.25 (TXD0/GPIO16)
USB_D+: D1.1 (I/O1_1)
USB_D-: D1.3 (I/O2_1)
VBAT: Q1.3 (D), TP3.TP, U5.2 (CELL), U5.3 (VDD)
VBBAT: C2_BAT.1, MCP73831.3 (VBAT)
VBUS: PFMF.050.1.2, TP14.TP
VRTC: C8.1, C10_SUPERCAP.1, R_CAPACITOR.2, U3.14 (VBAT)
VUSB: J2.A4, PFMF.050.1.1

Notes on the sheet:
RTC Module DS3231SN
Test Pads
Owiic / Stemma QT
SPI ESD Protection Lines
External NOR Flash 64MB
DMG2305UX-7
USB C connector & ESD protection
LDO Voltage Regulator
SD Card
Display Type Selector
E-Paper Drive Circuit
Li-Po Battery Charging Controller
ESP32 C6
E-Paper Display Header
EPD Power
Environmental Sensor BME688
Voltage Supervisor + Reset & Boot / IO Button
Battery Charge Level

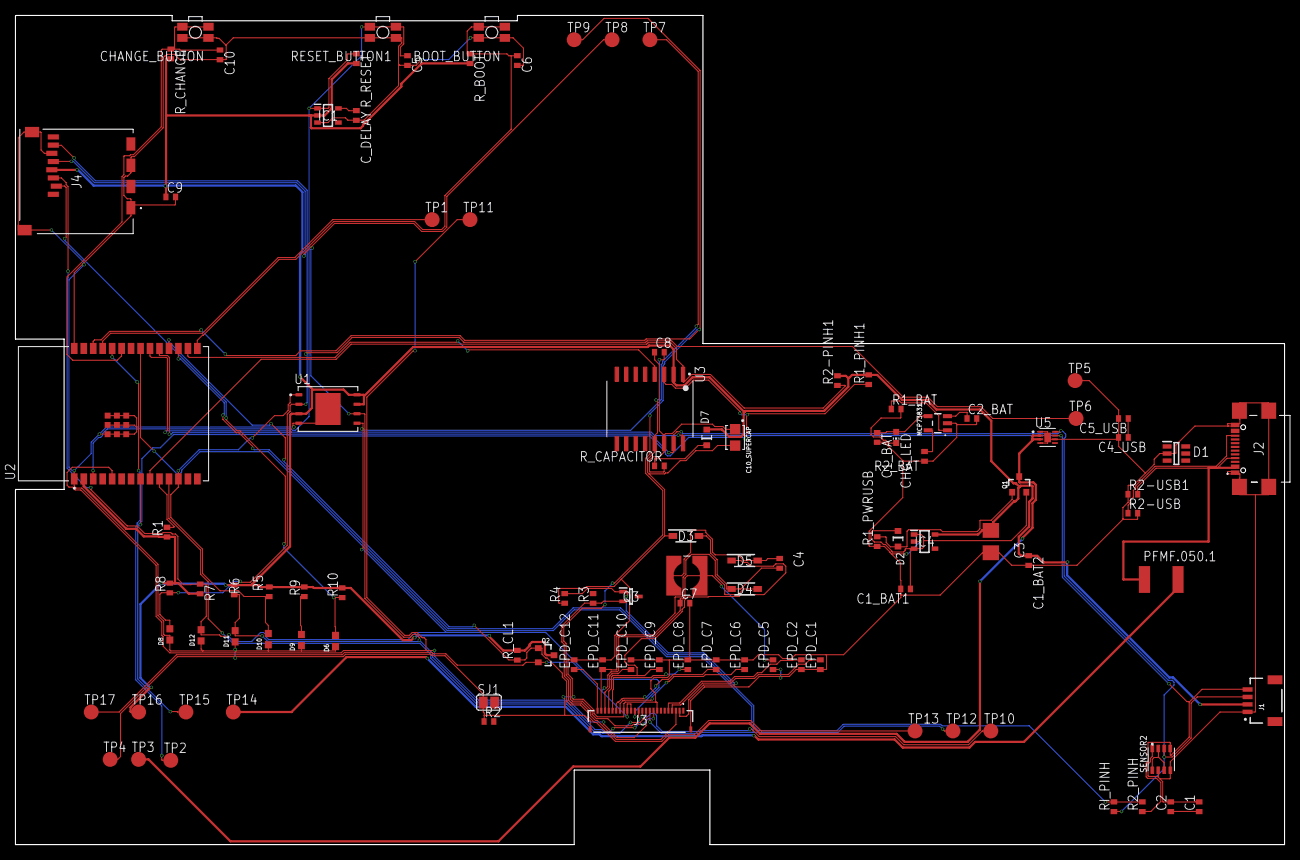
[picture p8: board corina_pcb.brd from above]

Board: 2 copper layers, 170.2 x 111.2 mm, 103 parts (0 on the bottom side), 57 nets.

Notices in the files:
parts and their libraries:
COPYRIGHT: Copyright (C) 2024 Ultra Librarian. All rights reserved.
